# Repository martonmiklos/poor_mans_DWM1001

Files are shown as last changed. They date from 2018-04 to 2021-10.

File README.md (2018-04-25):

# Poor man's DWM1001

(Or the rich one's it depends on the perspective.)

I happened to buy a few DWM1000s from the mouser. When they arrived I have realized that the Decawave have just released the DWM1001 modules with a supported software stack, etc. So I deciced to create a board which hosts a E73-2G4M04S BLE module and provides connection to my DWM1000 breakout boards. The HW provides the same connections what the DWM1001 has just in bigger size. 

Drawn in EAGLE 8.x

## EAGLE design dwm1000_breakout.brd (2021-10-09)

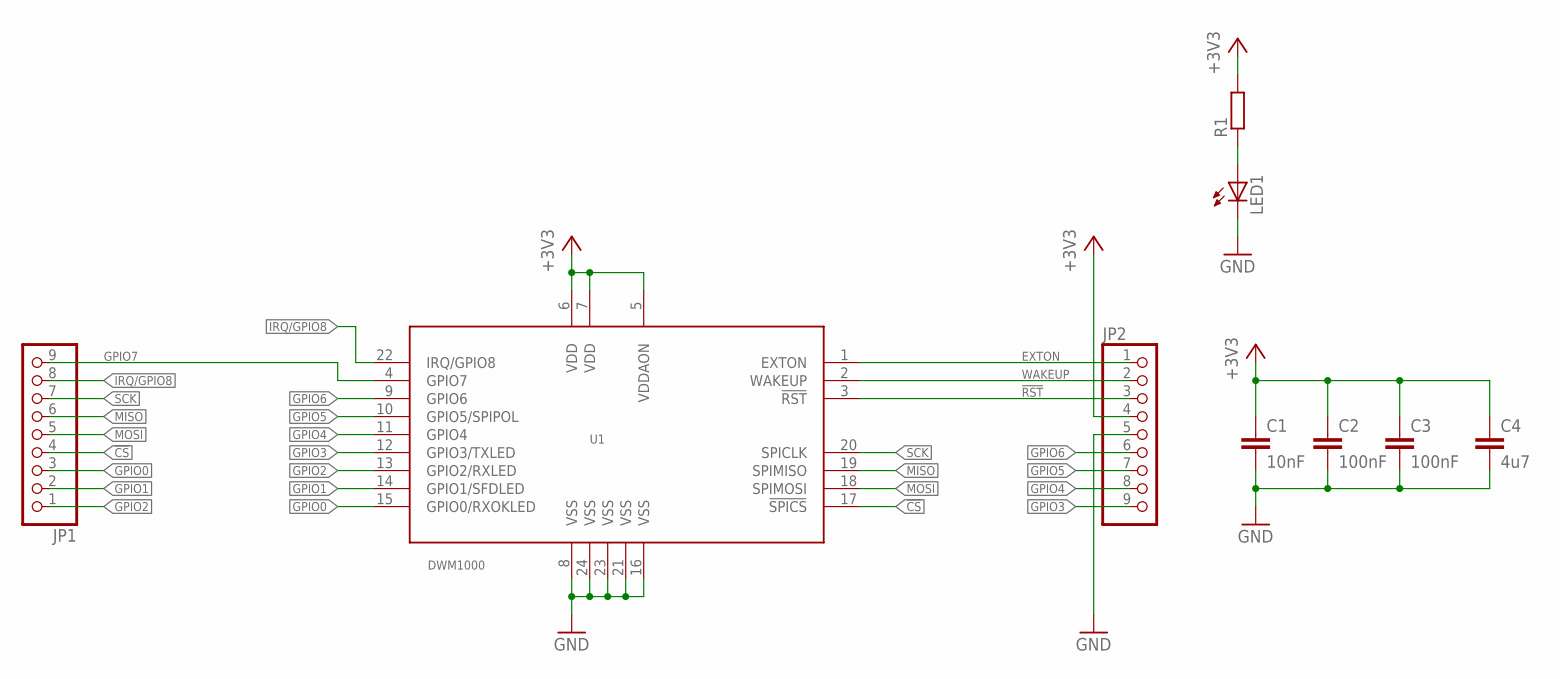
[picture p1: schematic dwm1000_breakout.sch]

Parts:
C1: 10nF; C0603
C2, C3: 100nF; C0603
C4: 4u7; C0805K
JP1, JP2: PINHD-1X9; 1X09
LED1: LEDCHIP-LED0603; CHIP-LED0603
R1: R-EU_R0603; R0603
U1: DWM1000

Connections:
!CS: JP1.4, U1.17 (!SPICS)
!RST: JP2.3, U1.3 (!RST)
+3V3: C1.1, C2.1, C3.1, C4.1, JP2.4, R1.2, U1.5 (VDDAON), U1.6 (VDD), U1.7 (VDD)
EXTON: JP2.1, U1.1 (EXTON)
GND: C1.2, C2.2, C3.2, C4.2, JP2.5, LED1.C, U1.8 (VSS), U1.16 (VSS), U1.21 (VSS), U1.23 (VSS), U1.24 (VSS)
GPIO0: JP1.3, U1.15 (GPIO0/RXOKLED)
GPIO1: JP1.2, U1.14 (GPIO1/SFDLED)
GPIO2: JP1.1, U1.13 (GPIO2/RXLED)
GPIO3: JP2.9, U1.12 (GPIO3/TXLED)
GPIO4: JP2.8, U1.11 (GPIO4)
GPIO5: JP2.7, U1.10 (GPIO5/SPIPOL)
GPIO6: JP2.6, U1.9 (GPIO6)
GPIO7: JP1.9, U1.4 (GPIO7)
IRQ/GPIO8: JP1.8, U1.22 (IRQ/GPIO8)
MISO: JP1.6, U1.19 (SPIMISO)
MOSI: JP1.5, U1.18 (SPIMOSI)
unnamed: LED1.A, R1.1
SCK: JP1.7, U1.20 (SPICLK)
WAKEUP: JP2.2, U1.2 (WAKEUP)

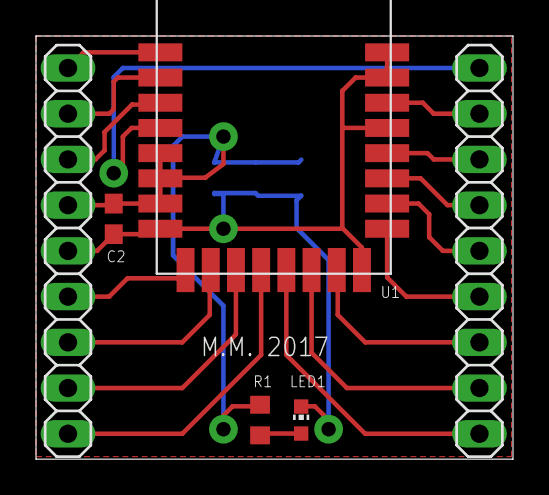
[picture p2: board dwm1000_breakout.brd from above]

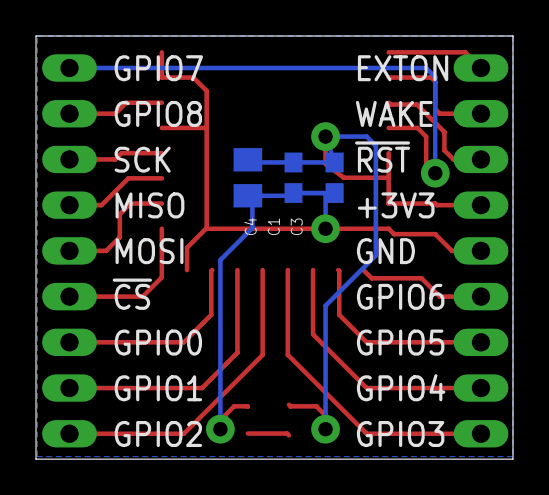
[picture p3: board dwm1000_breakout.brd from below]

Board: 2 copper layers, 26.5 x 23.5 mm, 9 parts (3 on the bottom side), 19 nets.

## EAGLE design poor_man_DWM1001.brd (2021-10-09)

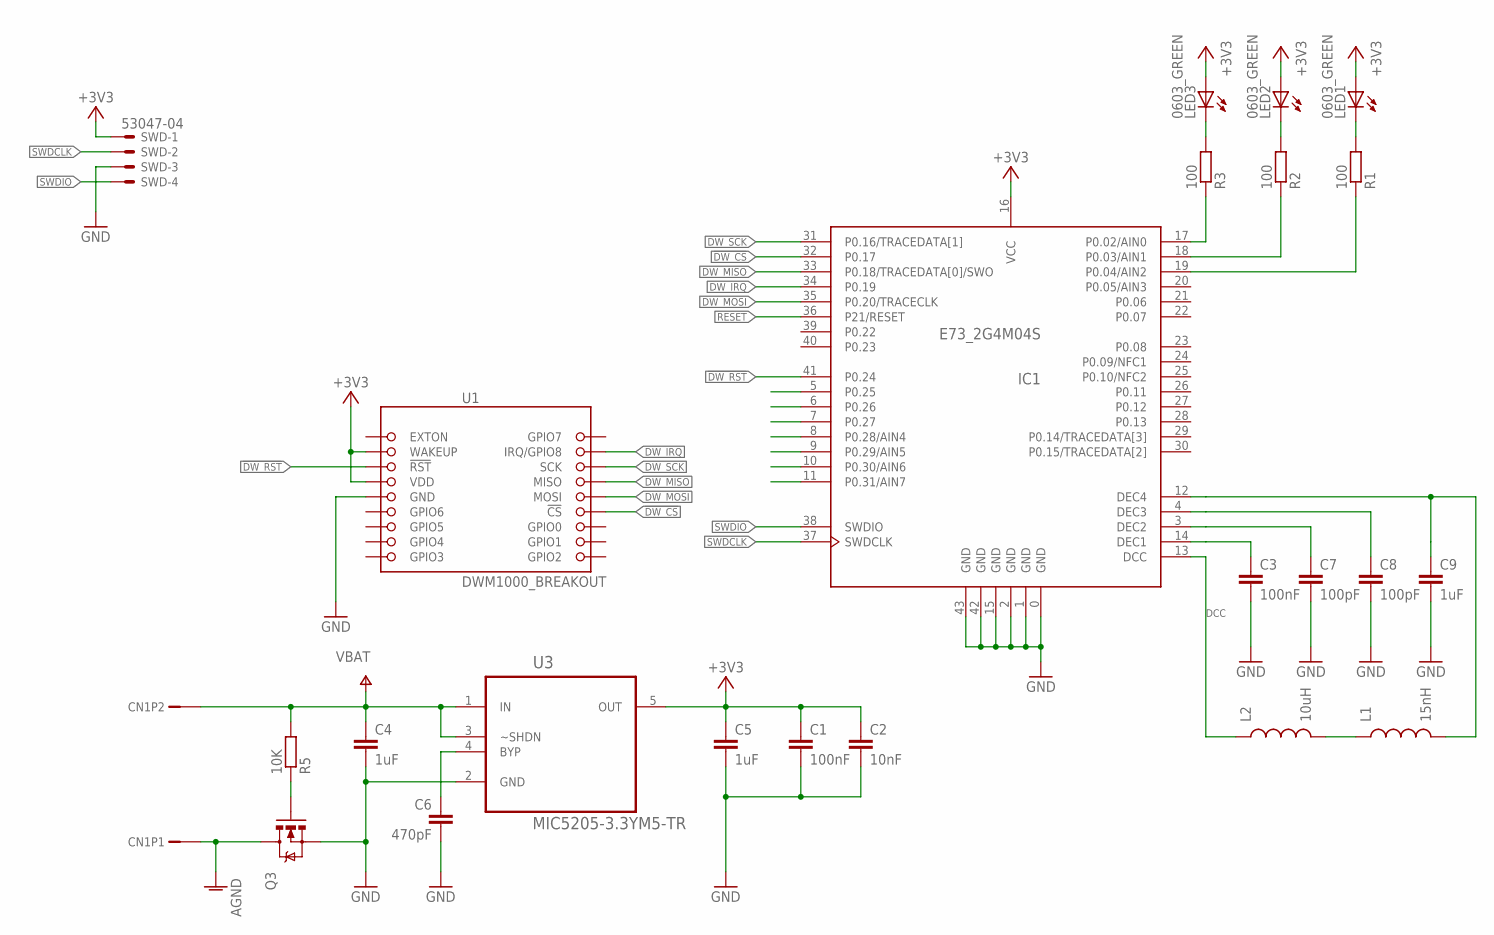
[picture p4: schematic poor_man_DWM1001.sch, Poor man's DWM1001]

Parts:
C1, C3: 100nF; C0603
C2: 10nF; C0603
C4, C5, C9: 1uF; C0603
C6: 470pF; C0603
C7, C8: 100pF; C0603
CN1: B2B-PH-K-S
IC1: E73_2G4M04S
L1: 15nH; SPARKFUN_C0402
L2: 10uH; SPARKFUN_0603
LED1, LED2, LED3: 0603_GREEN; CHIP-LED0603
Q3: MOSFET-NCHANNELSMD; SOT23-3
R1, R2, R3: 100; R0603
R5: 10K; R0603
SWD: 53047-04
U1: DWM1000_BREAKOUT
U3: MIC5205-3.3YM5-TR; SOT95P280X145-5N

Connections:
!DW_CS: IC1.32 (P0.17), U1.6 (!CS)
!DW_RST: IC1.41 (P0.24), U1.16 (!RST)
+3V3: C1.1, C2.1, C5.1, IC1.16 (VCC), LED1.A, LED2.A, LED3.A, SWD.1, U1.15 (VDD), U1.17 (WAKEUP), U3.5 (OUT)
AGND: CN1.1, Q3.3 (D)
ANTISTUPID_GATE: Q3.1 (G), R5.1
DCC: IC1.13 (DCC), L2.1
DEC1: C3.1, IC1.14 (DEC1)
DEC2: C7.1, IC1.3 (DEC2)
DEC3: C8.1, IC1.4 (DEC3)
DEC4: C9.1, IC1.12 (DEC4), L1.2
DW_IRQ: IC1.34 (P0.19), U1.2 (IRQ/GPIO8)
DW_MISO: IC1.33 (P0.18/TRACEDATA[0]/SWO), U1.4 (MISO)
DW_MOSI: IC1.35 (P0.20/TRACECLK), U1.5 (MOSI)
DW_SCK: IC1.31 (P0.16/TRACEDATA[1]), U1.3 (SCK)
GND: C1.2, C2.2, C3.2, C4.2, C5.2, C6.2, C7.2, C8.2, C9.2, IC1.0 (GND), IC1.1 (GND), IC1.2 (GND), IC1.15 (GND), IC1.42 (GND), IC1.43 (GND), Q3.2 (S), SWD.3, U1.14 (GND), U3.2 (GND)
GPIO_LED1: IC1.19 (P0.04/AIN2), R1.1
GPIO_LED1_R: LED1.C, R1.2
GPIO_LED2: IC1.18 (P0.03/AIN1), R2.1
GPIO_LED2_R: LED2.C, R2.2
GPIO_LED3: IC1.17 (P0.02/AIN0), R3.1
GPIO_LED3_R: LED3.C, R3.2
MIC_BYPASS: C6.1, U3.4 (BYP)
unnamed: L1.1, L2.2
RESET: IC1.36 (P21/RESET)
SWDCLK: IC1.37 (SWDCLK), SWD.2
SWDIO: IC1.38 (SWDIO), SWD.4
VBAT: C4.1, CN1.2, R5.2, U3.1 (IN), U3.3 (~SHDN)

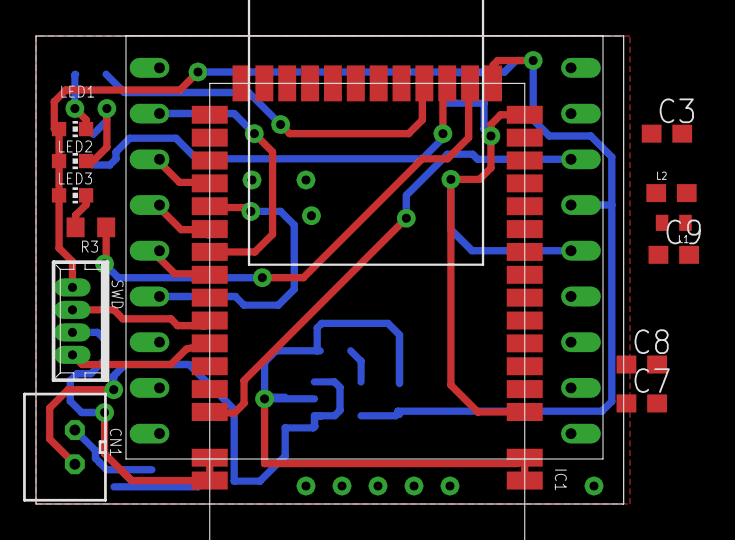
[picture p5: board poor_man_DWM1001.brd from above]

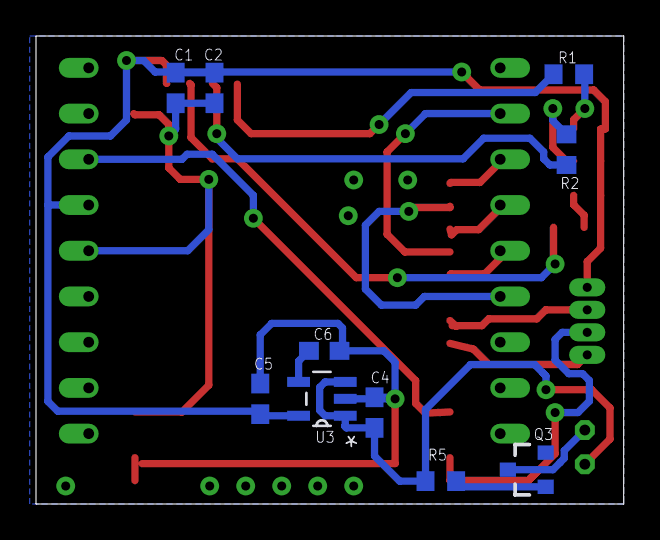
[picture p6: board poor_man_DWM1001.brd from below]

Board: 2 copper layers, 32.6 x 26.0 mm, 24 parts (10 on the bottom side), 26 nets.

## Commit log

2018-04-25 Initial add
    [poor_man_DWM1001.brd, poor_man_DWM1001.sch]
2018-04-26 Daily save
    [poor_man_DWM1001.brd, poor_man_DWM1001.sch]
2018-04-26 Silkscreen fixes
    [poor_man_DWM1001.brd]
2018-04-26 - Updated net names
    [poor_man_DWM1001.brd, poor_man_DWM1001.sch]
2021-10-09 Added DWM1000 board
    [dwm1000_breakout.brd, dwm1000_breakout.sch, poor_man_DWM1001.brd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]

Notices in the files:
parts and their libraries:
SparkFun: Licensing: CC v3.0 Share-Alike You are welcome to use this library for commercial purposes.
